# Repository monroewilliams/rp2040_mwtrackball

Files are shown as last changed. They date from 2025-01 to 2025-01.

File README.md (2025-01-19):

# rp2040-based trackball main board

This work is based on version 2 of the "rp2040 Minimal KiCad" sample provided by the Raspberry Pi foundation [here](https://datasheets.raspberrypi.com/rp2040/Minimal-KiCAD.zip).

It is inspired by (although not directly based on) jfedor2's excellent [RP2040+PMW3360 board](https://github.com/jfedor2/rp2040-pmw3360). (Although I did borrow the USB header pinout directly from that project.)

I've modified it for the specific needs of [my trackball design](https://github.com/monroewilliams/trackball), with a few other additions that may make it useful for other experimentation as well. I intend it to pair with a [breakout board design](https://github.com/monroewilliams/pmw3360-breakout) with matching JST plugs so that off-the-shelf cables can be used for assembly (instead of the hand-built sensor cables the old design needed).

The overall dimensions of the board match the dimensions of the mini-breadboard I used in the original trackball design. This is not a coincidence. ;) 

The SPI connectors are 6 pin JST-SH (1.0mm pitch), with a pinout based on [Pmod type 2](https://en.wikipedia.org/wiki/Pmod_Interface). This should match the connectors on the sensor breakout board linked above, allowing assembly using off-the-shelf 6-pin JST-SH cables. The cables need to be straight-through, not "crossed" (i.e. connect pin 1 to pin 1, etc.). I've included two SPI connectors attached to one set of SPI pins but with distinct cable select lines (labelled SPI0.x), and a third connector attached to a second set of SPI pins (SPI1.x). The number after the decimal point is the GPIO number of the cable select pin routed to each connector. The trackball design works fine with both sensors on the same SPI bus, but I expect the second bus may be useful for other experiments (such as connecting a display), and I wanted to have some flexibility to play with that.

The button connectors are also JST-SH, but just two pins each (signal and ground), with the intention that off-the-shelf "pigtail" JST cables can be soldered to microswitches for assembly. They are labelled with the number of the GPIO pin they're connected to.

There's also an on-board surface mount piezo speaker, which my trackball design uses to generate scrolling clicks when using twist-to-scroll. It should be usable for other speaker-related duties as needed.

Additionally, I added a connector that is compatible with Adafruit's ["STEMMA QT" I2C connection](https://learn.adafruit.com/introducing-adafruit-stemma-qt/what-is-stemma), and an additional 6 pin JST-SH breakout connector for a few of the other unused pins on the rp2040 (GPIOs 26-29, which happen to be the ADC-capable pins, as well as power and ground).

The final connector is a SWD debug plug that should conform to the [Raspberry Pi 3-pin Debug Connector Specification](https://datasheets.raspberrypi.com/debug/debug-connector-specification.pdf)

And just to finish things off, I included a NeoPixel (a.k.a. WS2812) RGB LED. Adding this to the board bumps it from JLCPCB's "Economic" tier to their "Standard" tier, which is a bit more expensive, so if you're having a batch of these made and would rather go the cheaper route it can just be omitted (just choose not to place it when reviewing the BOM after upload).  This same component is sold in packs of 10 by Adafruit [here](https://www.adafruit.com/product/4684), so it could be added after the fact (assuming you're willing to hand-solder a 2mm square SMD component).

Any issues with the changes I made to this layout are solely my fault. I've attempted to maintain the spirit of the rp2040 reference design, but this is my first attempt at designing a board with a microcontroller, so it would not surprise me if it has problems. Caveat emptor, etc, etc.

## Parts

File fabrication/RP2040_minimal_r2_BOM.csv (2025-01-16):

Designator | Comment | Footprint | DNP | LCSC
Y1 | X322512MSB4SI | Crystal:Crystal_SMD_3225-4Pin_3.2x2.5mm |  | C9002
U3 | RP2040 | RP2040_minimal:RP2040-QFN-56 |  | C2040
U2 | W25Q128JVS | RP2040_minimal:WSON-8-1EP_6x5mm_P1.27mm_EP3.4x4.3mm |  | C190862
U1 | AP2112K-3.3TRG1 | RP2040_minimal:SOT-23-5 |  | C51118
SW1,SW2 | -- mixed values -- | Button_Switch_SMD:SW_SPST_B3U-1000P |  | C498294
R6,R7 | 100 | Resistor_SMD:R_0402_1005Metric |  | C25076
R3,R4 | 27 | Resistor_SMD:R_0402_1005Metric |  | C274349
R2 | 10k | Resistor_SMD:R_0402_1005Metric |  | C25744
R1,R5 | 1k | Resistor_SMD:R_0402_1005Metric |  | C11702
LS1 | PIEZO | Buzzer_Beeper:Buzzer_Murata_PKMCS0909E |  | C910763
J13 | SWD | RP2040_minimal:JST_SH_BM03B-SRSS-TB_1x03-1MP_P1.00mm_Vertical |  | C160389
J6,J7,J8,J9,J10,J11 | -- mixed values -- | RP2040_minimal:JST_SH_BM02B-SRSS-TB_1x02-1MP_P1.00mm_Vertical |  | C160388
J5 | USB | RP2040_minimal:JST_XH_B4B-XH-A_1x04_P2.50mm_Vertical |  | C7429634
J4 | I²C0 | Connector_JST:JST_SH_BM04B-SRSS-TB_1x04-1MP_P1.00mm_Vertical |  | C160390
J1,J2,J3,J12 | -- mixed values -- | RP2040_minimal:JST_SH_BM06B-SRSS-TB_1x06-1MP_P1.00mm_Vertical |  | C7430455
D1 | WS2812B-2020 | LED_SMD:LED_WS2812B-2020_PLCC4_2.0x2.0mm |  | C965555
C8,C10 | 1u | Capacitor_SMD:C_0402_1005Metric |  | C307331
C5,C6,C7,C9,C11,C12,C13,C14,C15,C16 | 100n | Capacitor_SMD:C_0402_1005Metric |  | C126504
C2,C3 | 15p | Capacitor_SMD:C_0402_1005Metric |  | C1548
C1,C4,C17 | 10u | Capacitor_SMD:C_0805_2012Metric |  | C15850

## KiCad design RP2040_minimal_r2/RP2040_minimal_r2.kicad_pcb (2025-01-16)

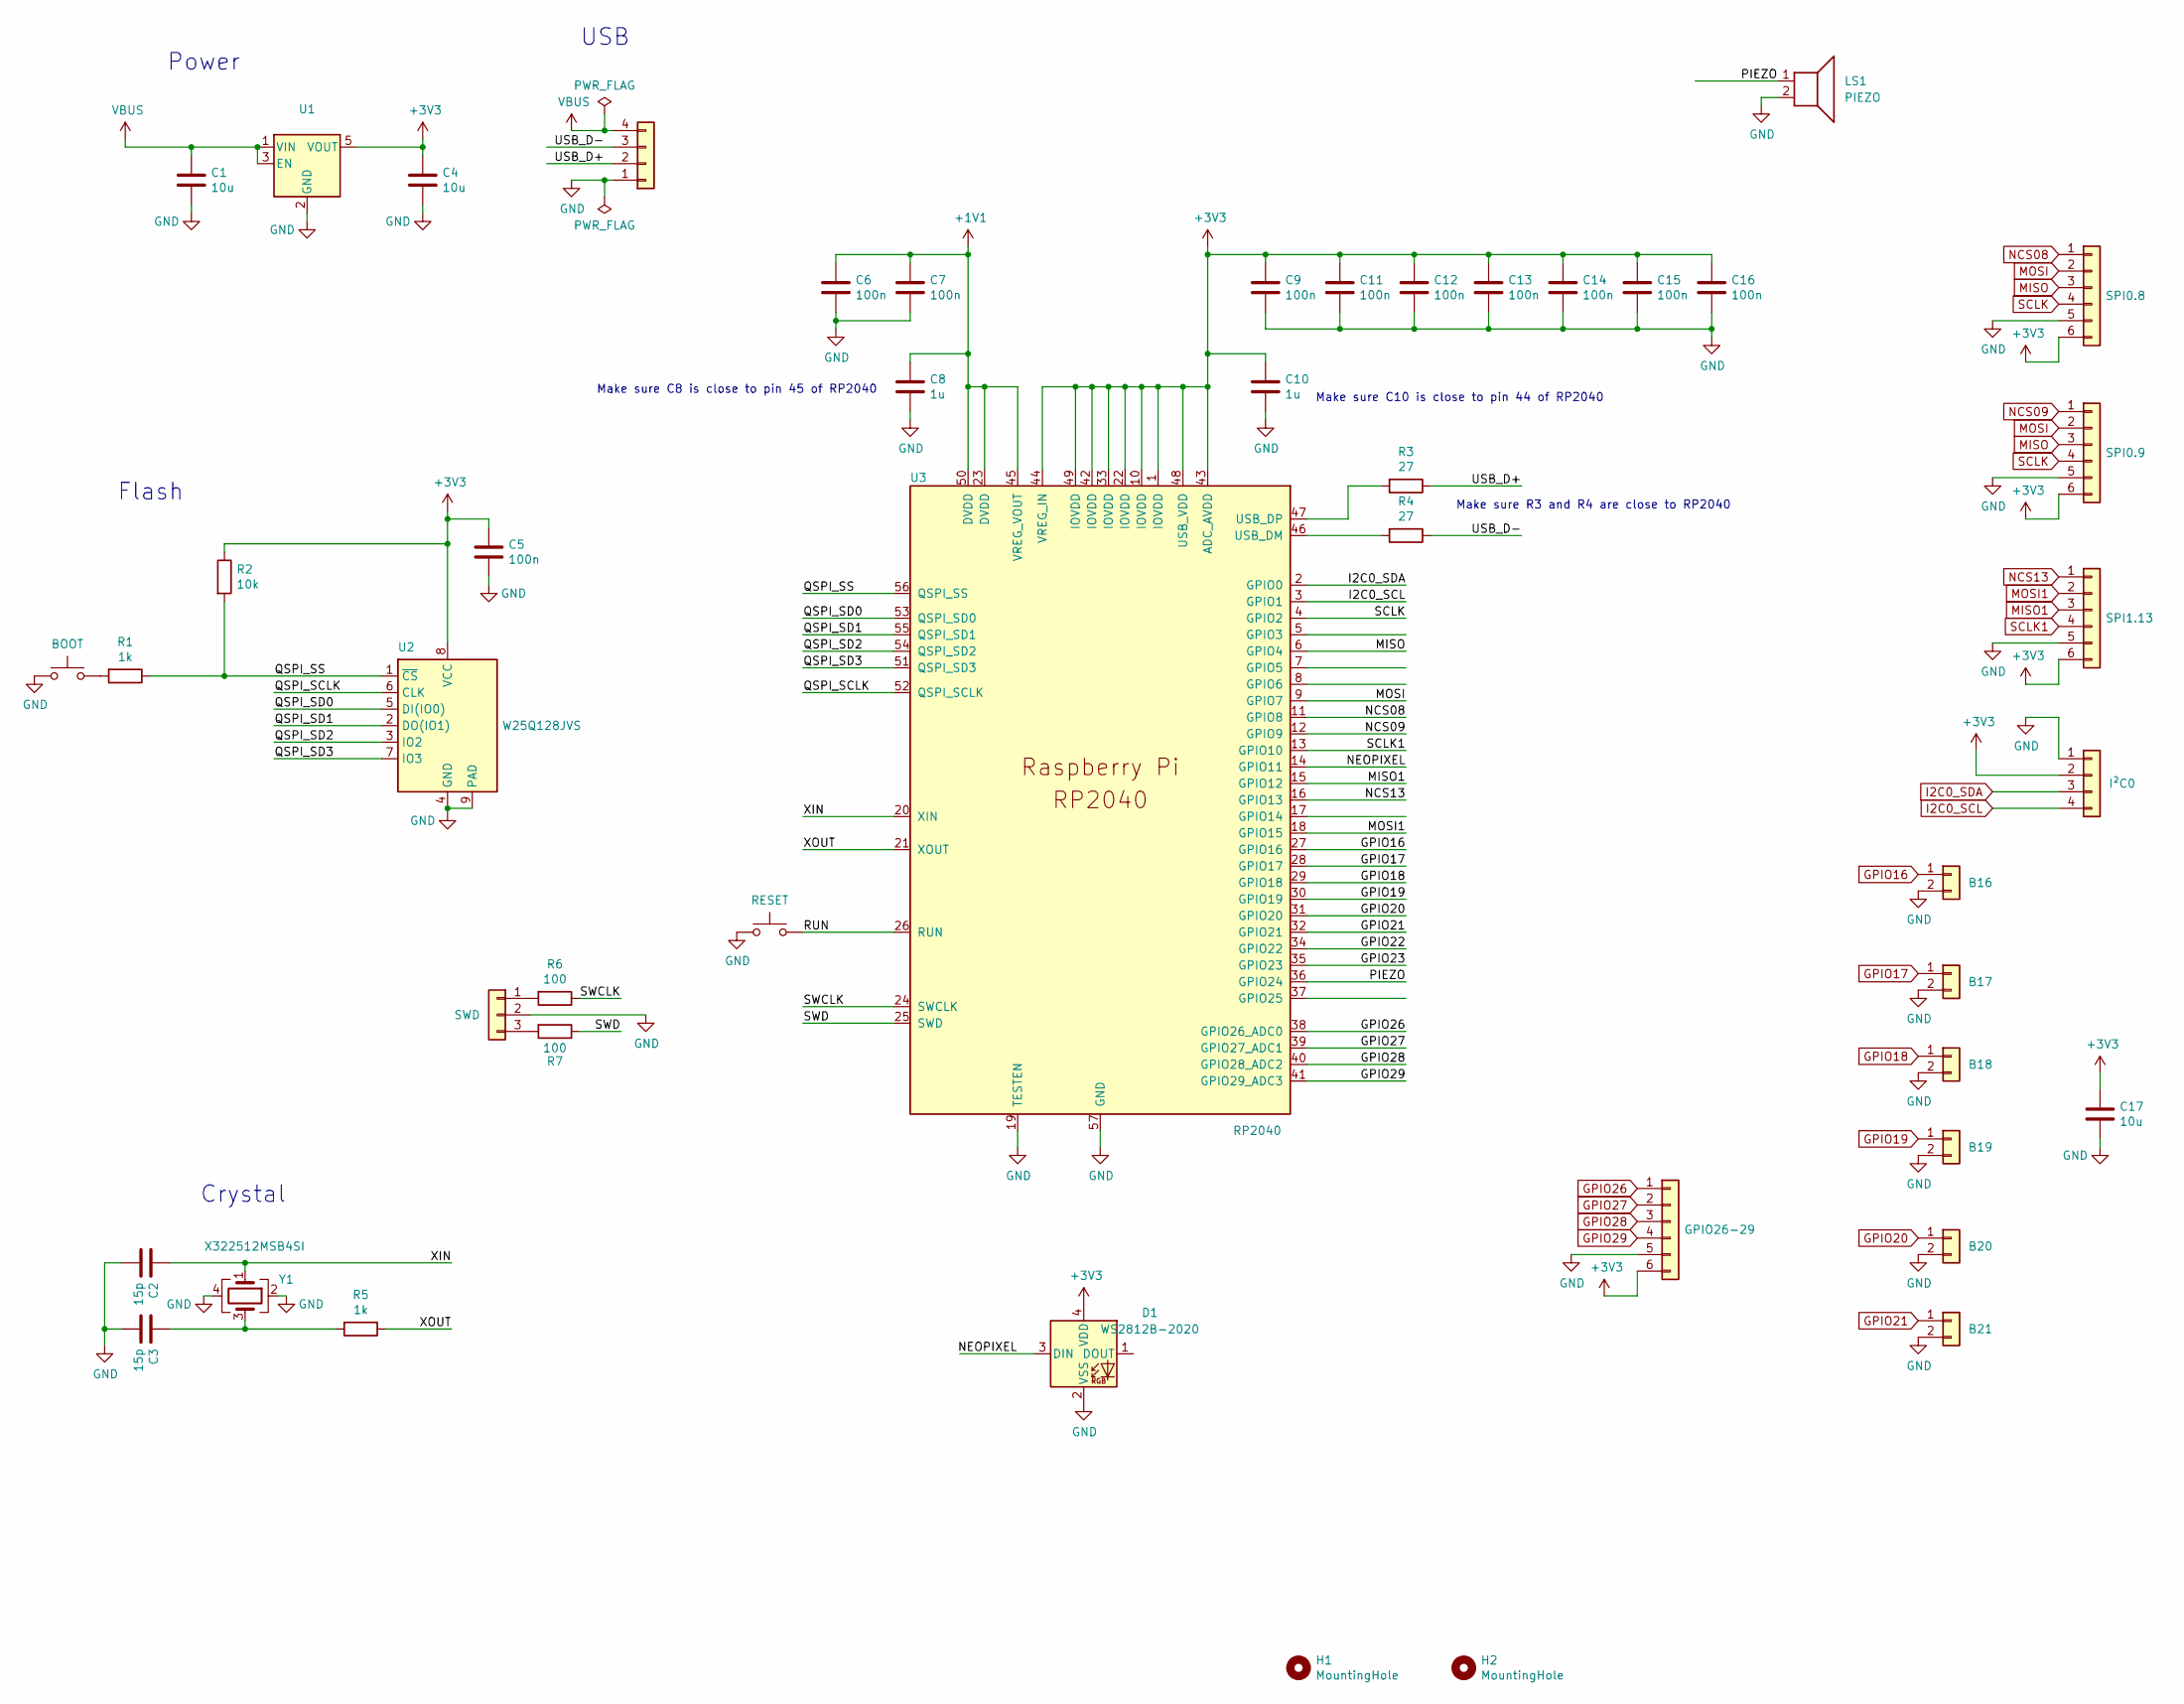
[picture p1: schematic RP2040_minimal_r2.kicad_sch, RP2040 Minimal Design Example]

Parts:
C1, C4, C17: 10u; C_0805_2012Metric; LCSC C15850
C2, C3: 15p; C_0402_1005Metric; LCSC C1548
C5, C6, C7, C9, C11, C12, C13, C14, C15, C16: 100n; C_0402_1005Metric; LCSC C126504
C8, C10: 1u; C_0402_1005Metric; LCSC C307331
D1: WS2812B-2020; LED_WS2812B-2020_PLCC4_2.0x2.0mm; LCSC C965555
H1, H2: MountingHole; MountingHole_2.2mm_M2
J1: SPI0.8; JST_SH_BM06B-SRSS-TB_1x06-1MP_P1.00mm_Vertical; LCSC C7430455
J2: SPI0.9; JST_SH_BM06B-SRSS-TB_1x06-1MP_P1.00mm_Vertical; LCSC C7430455
J3: SPI1.13; JST_SH_BM06B-SRSS-TB_1x06-1MP_P1.00mm_Vertical; LCSC C7430455
J4: I²C0; JST_SH_BM04B-SRSS-TB_1x04-1MP_P1.00mm_Vertical; LCSC C160390
J5: USB; JST_XH_B4B-XH-A_1x04_P2.50mm_Vertical; LCSC C7429634
J6: B16; JST_SH_BM02B-SRSS-TB_1x02-1MP_P1.00mm_Vertical; LCSC C160388
J7: B17; JST_SH_BM02B-SRSS-TB_1x02-1MP_P1.00mm_Vertical; LCSC C160388
J8: B18; JST_SH_BM02B-SRSS-TB_1x02-1MP_P1.00mm_Vertical; LCSC C160388
J9: B19; JST_SH_BM02B-SRSS-TB_1x02-1MP_P1.00mm_Vertical; LCSC C160388
J10: B20; JST_SH_BM02B-SRSS-TB_1x02-1MP_P1.00mm_Vertical; LCSC C160388
J11: B21; JST_SH_BM02B-SRSS-TB_1x02-1MP_P1.00mm_Vertical; LCSC C160388
J12: GPIO26-29; JST_SH_BM06B-SRSS-TB_1x06-1MP_P1.00mm_Vertical; LCSC C7430455
J13: SWD; JST_SH_BM03B-SRSS-TB_1x03-1MP_P1.00mm_Vertical; LCSC C160389
LS1: PIEZO; Buzzer_Murata_PKMCS0909E; LCSC C910763
R1, R5: 1k; R_0402_1005Metric; LCSC C11702
R2: 10k; R_0402_1005Metric; LCSC C25744
R3, R4: 27; R_0402_1005Metric; LCSC C274349
R6, R7: 100; R_0402_1005Metric; LCSC C25076
SW1: BOOT; SW_SPST_B3U-1000P; LCSC C498294
SW2: RESET; SW_SPST_B3U-1000P; LCSC C498294
U1: AP2112K-3.3TRG1; SOT-23-5; LCSC C51118
U2: W25Q128JVS; WSON-8-1EP_6x5mm_P1.27mm_EP3.4x4.3mm; LCSC C190862
U3: RP2040; RP2040-QFN-56; LCSC C2040
Y1: X322512MSB4SI; Crystal_SMD_3225-4Pin_3.2x2.5mm; LCSC C9002

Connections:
+1V1: C6.1, C7.1, C8.1, U3.23 (DVDD), U3.45 (VREG_VOUT), U3.50 (DVDD)
+3V3: C4.1, C5.1, C9.1, C10.1, C11.1, C12.1, C13.1, C14.1, C15.1, C16.1, C17.1, D1.4 (VDD), J1.6, J2.6, J3.6, J4.2, J12.6, R2.1, U1.5 (VOUT), U2.8 (VCC), U3.1 (IOVDD), U3.10 (IOVDD), U3.22 (IOVDD), U3.33 (IOVDD), U3.42 (IOVDD), U3.43 (ADC_AVDD), U3.44 (VREG_IN), U3.48 (USB_VDD), U3.49 (IOVDD)
/GPIO22: U3.34 (GPIO22)
/GPIO23: U3.35 (GPIO23)
/NEOPIXEL: D1.3 (DIN), U3.14 (GPIO11)
/PIEZO: LS1.1, U3.36 (GPIO24)
/QSPI_SCLK: U2.6 (CLK), U3.52 (QSPI_SCLK)
/QSPI_SD0: U2.5 (DI(IO0)), U3.53 (QSPI_SD0)
/QSPI_SD1: U2.2 (DO(IO1)), U3.55 (QSPI_SD1)
/QSPI_SD2: U2.3 (IO2), U3.54 (QSPI_SD2)
/QSPI_SD3: U2.7 (IO3), U3.51 (QSPI_SD3)
/QSPI_SS: R1.1, R2.2, U2.1 (~CS), U3.56 (QSPI_SS)
/RUN: SW2.2, U3.26 (RUN)
/SWCLK: R6.1, U3.24 (SWCLK)
/SWD: R7.1, U3.25 (SWD)
/USB_D+: J5.2, R3.1
/USB_D-: J5.3, R4.1
/XIN: C2.1, U3.20 (XIN), Y1.1
/XOUT: R5.1, U3.21 (XOUT)
GND: C1.2, C2.2, C3.2, C4.2, C5.2, C6.2, C7.2, C8.2, C9.2, C10.2, C11.2, C12.2, C13.2, C14.2, C15.2, C16.2, C17.2, D1.2 (VSS), J1.5, J2.5, J3.5, J4.1, J5.1, J6.2, J7.2, J8.2, J9.2, J10.2, J11.2, J12.5, J13.2, LS1.2, SW1.1, SW2.1, U1.2 (GND), U2.4 (GND), U2.9 (PAD), U3.19 (TESTEN), U3.57 (GND), Y1.2, Y1.4
GPIO16: J6.1, U3.27 (GPIO16)
GPIO17: J7.1, U3.28 (GPIO17)
GPIO18: J8.1, U3.29 (GPIO18)
GPIO19: J9.1, U3.30 (GPIO19)
GPIO20: J10.1, U3.31 (GPIO20)
GPIO21: J11.1, U3.32 (GPIO21)
GPIO26: J12.1, U3.38 (GPIO26_ADC0)
GPIO27: J12.2, U3.39 (GPIO27_ADC1)
GPIO28: J12.3, U3.40 (GPIO28_ADC2)
GPIO29: J12.4, U3.41 (GPIO29_ADC3)
I2C0_SCL: J4.4, U3.3 (GPIO1)
I2C0_SDA: J4.3, U3.2 (GPIO0)
MISO: J1.3, J2.3, U3.6 (GPIO4)
MISO1: J3.3, U3.15 (GPIO12)
MOSI: J1.2, J2.2, U3.9 (GPIO7)
MOSI1: J3.2, U3.18 (GPIO15)
NCS08: J1.1, U3.11 (GPIO8)
NCS09: J2.1, U3.12 (GPIO9)
NCS13: J3.1, U3.16 (GPIO13)
unnamed: C3.1, R5.2, Y1.3
unnamed: J13.1, R6.2
unnamed: J13.3, R7.2
unnamed: R1.2, SW1.2
unnamed: R4.2, U3.46 (USB_DM)
unnamed: R3.2, U3.47 (USB_DP)
SCLK: J1.4, J2.4, U3.4 (GPIO2)
SCLK1: J3.4, U3.13 (GPIO10)
VBUS: C1.1, J5.4, U1.1 (VIN), U1.3 (EN)

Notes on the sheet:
Power
Crystal
Make sure C8 is close to pin 45 of RP2040
Make sure C10 is close to pin 44 of RP2040
USB
Make sure R3 and R4 are close to RP2040
Flash

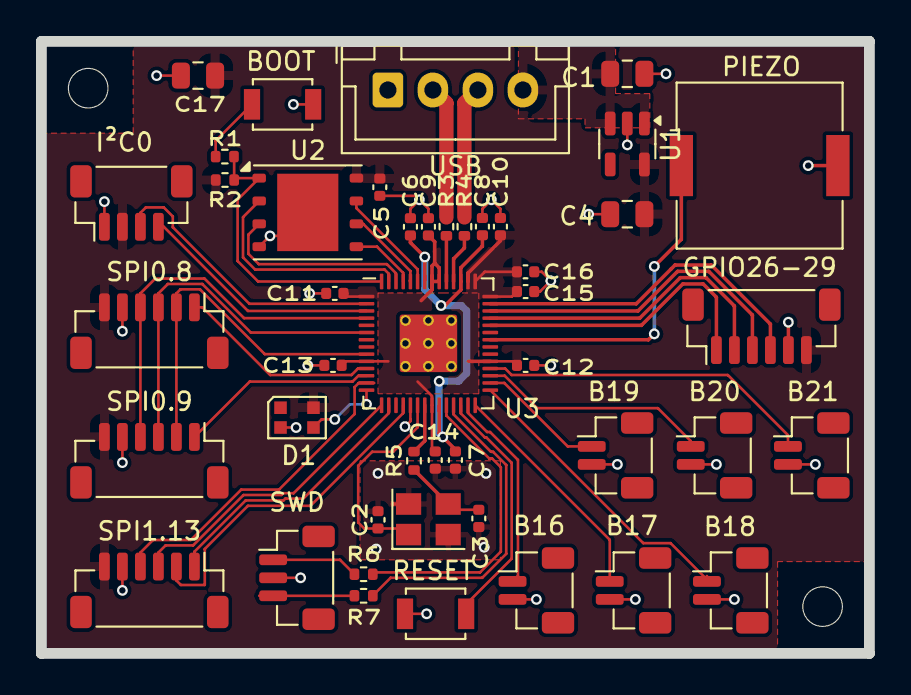
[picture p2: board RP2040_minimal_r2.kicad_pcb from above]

Board: 2 copper layers, 46.0 x 34.0 mm, 47 parts (0 on the bottom side), 46 nets.

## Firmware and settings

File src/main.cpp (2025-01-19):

#include "Adafruit_TinyUSB.h"
#include "Wire.h"

////////////////////////////////////////
// Various config options

// This is the frequency at which the loop will run.
const int loop_Hz = 2;

///// Uncomment the following to exercise various hardware

// Serial output over USB
// #define SERIAL_DEBUG

// Piezo speaker
#define TEST_PIEZO

// NeoPixel
#define TEST_NEOPIXEL

// i2c display (SSD1327, since that's what I have lying around right now)
#define TEST_I2C_SSD1327

//
//////////////////////////////////////////////

#if defined(TEST_NEOPIXEL)
  #include <Adafruit_NeoPixel.h>
  Adafruit_NeoPixel pixel(1, PIN_NEOPIXEL);
#endif

#if defined(TEST_I2C_SSD1327)
  #define TEST_DISPLAY_GRAY4 1
  #define TEST_DISPLAY_I2C 1
  #include <Adafruit_SSD1327.h>

  Adafruit_SSD1327 display(128, 128, &Wire, -1, 1000000UL);
  const int display_address = SSD1327_I2C_ADDRESS;
  const uint16_t text_color = SSD1327_WHITE;
  const uint16_t text_bg = SSD1327_BLACK;

  bool display_ready = false;

  void reset_display()
  {
    display.clearDisplay();
    display.fillScreen(text_bg);
    display.setTextSize(1);
    display.setTextWrap(true);
    display.setTextColor(text_color, text_bg);
    display.setCursor(0,0);

    // Leave room for live updates
    display.print("\n\n\n\n");
    display.print(F("It's alive!"));
    display.setContrast(0x7f);
    // display.setContrast(0x1f);
  }

  bool i2c_probe_bus()
  {
    // Check to see whether it looks like there's anything connected to the SDA/SCL pins.
    // This is needed because calling Wire.begin() without anything conneted seems to break things.
    // Specifically, it returns false positives and sometimes hangs the device.

    // If i2c is connected, both pins should have pull-up resistors, which means they will read high.
    pinMode(PIN_WIRE0_SDA, INPUT);
    pinMode(PIN_WIRE0_SCL, INPUT);
    return (digitalRead(PIN_WIRE0_SDA) == HIGH) && (digitalRead(PIN_WIRE0_SCL) == HIGH);
  }

  bool i2c_probe_device(byte address)
  {
    // Probe the specified address to see if a device seems to be present.
    Wire.beginTransmission(address);
    return (Wire.endTransmission() == 0);
  }

#endif

// HID report descriptor using TinyUSB's template
// Single Report (no ID) descriptor
uint8_t const desc_hid_report[] =
{
  TUD_HID_REPORT_DESC_MOUSE()
};

// USB HID object
Adafruit_USBD_HID usb_hid;

class DebugLogger: public Print
{
public:
	// Print subclass methods
    virtual size_t write(uint8_t);
    virtual size_t write(const uint8_t *buffer, size_t size);

	// Other stuff
	// Returns true iff the log is connected to something.
	// Can be used to skip expensive operations that are only done to generate logs.
	bool enabled();
};

DebugLogger debugLogger;

size_t DebugLogger::write(uint8_t c)
{
  size_t result = 0;
#if defined(SERIAL_DEBUG)
  if (tud_cdc_connected())
  {
    result = Serial.write(c);
    yield();
  }
#endif

  return result;
}
size_t DebugLogger::write(const uint8_t *buffer, size_t size)
{
  size_t result = 0;
#if defined(SERIAL_DEBUG)
  if (tud_cdc_connected())
  {
    result = Serial.write(buffer, size);
    yield();
  }
#endif

  return result;
}

bool DebugLogger::enabled()
{
  bool result = false;
#if defined(SERIAL_DEBUG)
  if (tud_cdc_connected())
  {
    result = true;
  }
#endif
  return result;
}

void click()
{
#if !defined(PIEZO_FREQUENCY)
  #define PIEZO_FREQUENCY 5000
#endif

#if !defined(PIEZO_DURATION)
  #define PIEZO_DURATION 5
#endif

#ifdef PIN_PIEZO
  pinMode(PIN_PIEZO, OUTPUT);
  // This is MUCH louder than just toggling the high/low once with digitalWrite().
  tone(PIN_PIEZO, PIEZO_FREQUENCY, PIEZO_DURATION);
#endif
}

void setup() 
{
  // TinyUSB Setup
  USBDevice.setProductDescriptor("rp2040_mwtrackball");
  usb_hid.setStringDescriptor("rp2040_mwtrackball");
  usb_hid.setPollInterval(2);
  usb_hid.setReportDescriptor(desc_hid_report, sizeof(desc_hid_report));

  usb_hid.begin();

  // wait until device mounted
  while( !USBDevice.mounted() ) delay(1);

#if defined(SERIAL_DEBUG)
  Serial.begin(115200);

  // Wait for the serial port to be opened.
  // NOTE: this will block forever, which can be inconvenient if you're trying to use the device.
  while (!Serial);

  // alternate: add a short delay so I can get the console open before things start happening.
  // delay(2000);

  debugLogger.println(F("Opened serial port"));
#endif

#if defined(TEST_NEOPIXEL)
  pixel.begin();  // initialize the pixel
#endif

#if defined(TEST_I2C_SSD1327)
  if (!i2c_probe_bus())
  {
    debugLogger.println(F("i2c bus appears disconnected"));
  }
  else
  {
    debugLogger.println(F("i2c bus seems sane"));
    Wire.begin();
    if (!i2c_probe_device(display_address))
    {
      debugLogger.println(F("Display not found"));
    }
    else
    {
      debugLogger.println(F("Display found"));
      // Something responded at the correct address. Assume it's the display.
      if (!display.begin(display_address)) 
      {
        debugLogger.println(F("Display init failed"));
      }
      else
      {
        display_ready = true;
        debugLogger.println(F("Display initialized"));

        reset_display();
      }
    }
  }
#endif

  debugLogger.println(F("Initialization complete."));

}

const int loop_microseconds = 1000000 / loop_Hz;

void loop() 
{
  unsigned long loop_start_time = micros();
  // Time taken by the last loop, saved so we can display it during the next loop.
  static unsigned long loop_time = 0;

  debugLogger.println("Hello, world!");

#if defined(TEST_PIEZO)
  // Play a click for each loop
  click();
#endif

  static int pixel_color = 0;
  const int pixel_color_scale = 16;
  int red = (pixel_color & 0x03) * pixel_color_scale;
  int green = ((pixel_color >> 2) & 0x03) * pixel_color_scale;
  int blue = ((pixel_color >> 4) & 0x03) * pixel_color_scale;

#if defined(TEST_NEOPIXEL)
  pixel.setPixelColor(0, red, green, blue);
  pixel.show();
#endif

#if defined(TEST_I2C_SSD1327)
    if (display_ready)
    {
      display.clearDisplay();
      display.setTextSize(2);
      display.setCursor(0,0);

      display.print(F("R = "));
      display.print(red);
      display.print(F("\nG = "));
      display.print(green);
      display.print(F("\nB = "));
      display.print(blue);

      display.display();
    }
#endif

  pixel_color++;
  pixel_color &= 0x3F;

  // Delay to keep the loop time right around loop_microseconds
  loop_time = micros() - loop_start_time;
  if (loop_time < loop_microseconds)
  {
    delayMicroseconds(loop_microseconds - loop_time);
  }
}

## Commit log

2024-12-26 Initial import from https://datasheets.raspberrypi.com/rp2040/Minimal-KiCAD.zip Re-saved with current version of KiCad (8.0.7) Added "LCSC" field name to hold JLCPCB part numbers. Assigned JLCPCB par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
    NOTE that the column labels in the placement file are hard-coded, so these still have to be edited manually after every export before JLCPCB can process them.
    JLPCB wants these column names in the CPL (a.k.a. all-pos) file:
    Designator,Val,Package,Mid X, Mid Y,Rotation,Layer
    [RP2040_minimal_r2-B_Cu.gbr, RP2040_minimal_r2-B_Mask.gbr, RP2040_minimal_r2-B_Paste.gbr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]
2024-12-28 Reshape board to 46x34mm to match the footprint of the old breadboard. Replace some components (voltage regulator, flash memory chip, crystal) with ones that are cheaper and/or smaller Add BOOT/RESET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
    [RP2040_minimal_r2.kicad_pcb, RP2040_minimal_r2.kicad_sch]
2024-12-28 Change connectors to JST-SH 1.0mm Additional routing tweaks.
    [RP2040_minimal_r2.kicad_pcb, RP2040_minimal_r2.kicad_sch]
2024-12-28 Add I2C/STEMMA QT connector
    [RP2040_minimal_r2.kicad_pcb, RP2040_minimal_r2.kicad_sch]
2024-12-28 Added 6 button connectors. Added 6 pin breakout for GPIO 26-29 (includes ground and +3.3v as well).
    [RP2040_minimal_r2.kicad_pcb, RP2040_minimal_r2.kicad_sch]
2025-01-02 Update gerbers and BOM/placement files. Add readme file. Add github url to rear silkscreen layer. Clean up some old unused fill zones that I'd moved off to the side.
    [RP2040_minimal_r2-B_Cu.gbr, RP2040_minimal_r2-B_Mask.gbr, RP2040_minimal_r2-B_Paste.gbr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]
2025-01-03 Added a WS2812 LED (a.k.a. NeoPixel) Removed some top-side ground traces in favor of vias closer to ground pads. Updated the github URL. Minor changes to the readme.
    [RP2040_minimal_r2-B_Cu.gbr, RP2040_minimal_r2-B_Mask.gbr, RP2040_minimal_r2-B_Paste.gbr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]
2025-01-06 Fix incorrect pins used for SPI0. Changed button pins to GPIO 16-21 for slightly cleaner layout. Moved USB header closer to board edge, to allow JST-XH connector to be attached the other way around. 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
    [RP2040_minimal_r2-B_Cu.gbr, RP2040_minimal_r2-B_Mask.gbr, RP2040_minimal_r2-B_Paste.gbr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]
2025-01-15 Minor fixes to BOM generation settings.
2025-01-16 Update the USB connection to use a proper JST-XH footprint. Add local copies of several footprints that need to be tweaked to match JLCPCB's notion of component orientation/origin.
    [RP2040_minimal_r2-B_Cu.gbr, RP2040_minimal_r2-B_Mask.gbr, RP2040_minimal_r2-B_Paste.gbr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]
2025-01-16 Add SWD debug connector.
    [RP2040_minimal_r2-B_Cu.gbr, RP2040_minimal_r2-B_Mask.gbr, RP2040_minimal_r2-B_Paste.gbr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]
2025-01-19 Add a board variant, and example code that demonstrates how to use it with VS Code/PlatformIO.
